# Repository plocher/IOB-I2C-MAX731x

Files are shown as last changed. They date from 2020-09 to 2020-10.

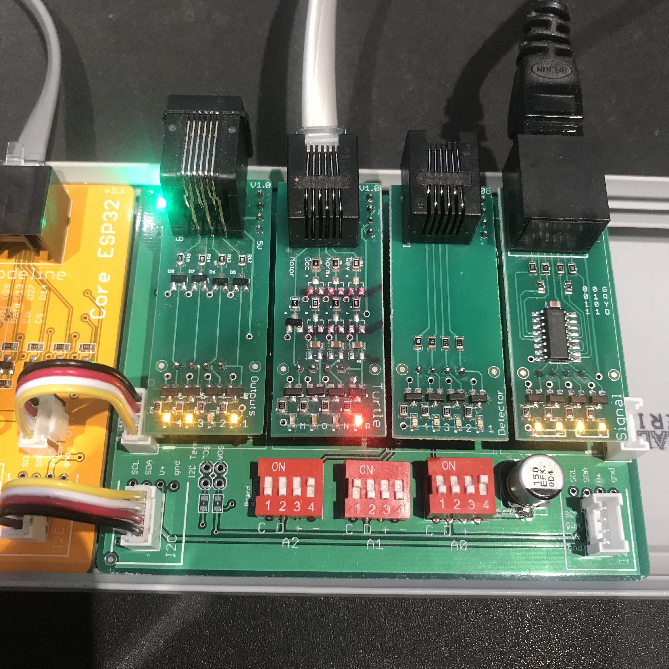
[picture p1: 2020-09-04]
IOB-I2C-MAX731x-photo.JPG

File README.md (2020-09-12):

# IOB-I2C-MAX731x
## License: CERN Open Hardware Licence v1.2

IOB I2C MAX7311/7318 based IO Expander

The MAX 731x series costs twice that of the MCP23017/PCA9555 expanders; for that price one gets support for  up to 64x devices on a single I2C chain.

### Specifications

This board is based on the MAX7311/7318 16 bit IO Expander, which supports up to 64x instances.

Each board provides a latched set of 16x IO points, with each point
being software selectable to be either an input or an output. The
individual points are reasonably protected from the environment, and can
sink 10 mA each (they are NOT current sources!)
By using active low inputs and outputs, the effects of environmental noise are
reduced - remote sensors only need to ground an I/O point to register
activity.

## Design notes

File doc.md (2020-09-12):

# IOB-I2C-MAX731x
## License: CERN Open Hardware Licence v1.2
### Introduction

IOB I2C MAX7311/7318 based IO Expander

The MAX 731x series costs twice that of the MCP23017/PCA9555 expanders; for that price one gets support for  up to 64x devices on a single I2C chain.

This board was originally produced to help me build control panels for
my model railroad - I needed to connect many different buttons, switches
and lights to an Arduino, and also connect the Arduino to a
communications bus (Ethernet, CAN or Loconet), and I couldn\'t find
anything that had both high IO point density AND visual feedback.

I started with a simple I2C based 32-pin Arduino
[IOShield](/pages/IOShield "wikilink") with monitoring LEDs on each pin
(Active-LOW inputs, LED is on when pin is grounded, writing a \"1\" to
the port pulls it to ground). I was aiming to support up to the max I2C
devices that can be used together, with the 8-bit board
[I2C-8574-IO](/pages/I2C-8574-IO "wikilink") (deprecated), that was a total of
8x boards with 128 i/o points.

The 7311 IO expanders used here will support up to 64 boards, with 1024
potential I/O points.

This latest design moves from overly generic and/or overly specialized
designs to a generic design with daughterboards that encapsulate the
appliance-specific buffering and logic. The benefits provided by these
IOB boards include:

-   Improved I/O bank utilization (leftover capacity is now a multiple
    of 4-bit daughtercard instead of 16-bit I2C card\...)
-   Riser height eliminates having to custom cut 3M track
-   Allows deprecation of cabling intensive signal driver IO4 and I2C
    boards
-   Allows custom circuitry to be added to Signal, Detector and Turtle
    drivers

### Cautions

With several hundred IO loads, and up to 256 external breakout devices,
a suitable power supply (or supplies) must be used.

In practice, a 3A 9-12VDC supply a good choice for most small to medium
sized control points.

This supply needs to power the core processor, its direct IO loads, the
I2C expander chain AND provide \~100mA to each IO4 device. Instead of
relying on the Arduino\'s onboard regulated supply (which is only good
for about 100mA itself), each board has its own regulator with a common
supply feed that can handle up to 4A @ 12v. If more power is needed, the
daisy chained power feed thru can be replaced with a per-board
independent supply.

### Specifications

This IO board is based on the MAX7311/18 16 bit IO Expander, mounted on a
[IOB Baseboard](/pages/IOB-Baseboard "wikilink") that presents a
bank of 4x I/O personality boards (IOBs). The Baseboard contains buffered LED drivers connected
to LEDs that show the status of the I/O lines in real time. They also
contain the needed circuitry to drive / sense the appliances connected
to them. See

-   [IOB-Inputs](/pages/IOB-Inputs "wikilink") 4x buffered inputs
-   [IOB-Outputs](/pages/IOB-Outputs "wikilink") 4x buffered outputs
-   [IOB-Turtle](/pages/IOB-Turtle "wikilink") 1x buffered output and 3x buffered inputs
-   [IOB-Generic](/pages/IOB-Generic "wikilink") 4x unbuffered I/O lines with optional inline resistors

Each board provides a latched set of 16x IO points, with each point
being software selectable to be either an input or an output. The
individual points are reasonably protected from the environment, and can
sink 10 mA each (they are NOT current sources!)
By using active low inputs and outputs, the effects of environmental noise are
reduced - remote sensors only need to ground an I/O point to register
activity.

### Communication Protocol

```C++
Simple I2C 16-bit Reads and Writes:
uint16_t I2Cexpander::read7311() {
    uint16_t data = 0;
    Wire.beginTransmission(_i2c_address);
    Wire.write(REGISTER_7311INPUT);
    Wire.endTransmission();
    // Wire.beginTransmission(_i2c_address);
    Wire.requestFrom(_i2c_address, (uint8_t)2);
    if(Wire.available()) {
        data = Wire.read();
    }
    if(Wire.available()) {
        data |= (Wire.read() << 8);
    }
    // Wire.endTransmission();
    return data;
}

void I2Cexpander::write7311(uint16_t data) {
    data = data | _config;
    Wire.beginTransmission(_i2c_address);
    Wire.write(REGISTER_7311OUTPUT);
    Wire.write(0xff & data);  //  low byte
    Wire.write(data >> 8);    //  high byte
    Wire.endTransmission();
}
```

See [I2Cexpander-lib](/pages/I2Cexpander "wikilink") for a more complete interface
library.

### Addressing
The address selection for the MAX731x is complex, as it uses 3x address pins, but adds SDA and SCL to the traditional "Vcc and Gnd" used elsewhere.

**AD2**|**AD1**|**AD0**|**A6**|**A5**|**A4**|**A3**|**A2**|**A1**|**A0**|**ADDRESS (HEX)**
:-----:|:-----:|:-----:|:-----:|:-----:|:-----:|:-----:|:-----:|:-----:|:-----:|:-----:
GND|SCL|GND|0|0|1|0|0|0|0|0x20
GND|SCL|V+|0|0|1|0|0|0|1|0x22
GND|SDA|GND|0|0|1|0|0|1|0|0x24
GND|SDA|V+|0|0|1|0|0|1|1|0x26
V+|SCL|GND|0|0|1|0|1|0|0|0x28
V+|SCL|V+|0|0|1|0|1|0|1|0x2A
V+|SDA|GND|0|0|1|0|1|1|0|0x2C
V+|SDA|V+|0|0|1|0|1|1|1|0x2E
GND|SCL|SCL|0|0|1|1|0|0|0|0x30
GND|SCL|SDA|0|0|1|1|0|0|1|0x32
GND|SDA|SCL|0|0|1|1|0|1|0|0x34
GND|SDA|SDA|0|0|1|1|0|1|1|0x36
V+|SCL|SCL|0|0|1|1|1|0|0|0x38
V+|SCL|SDA|0|0|1|1|1|0|1|0x3A
V+|SDA|SCL|0|0|1|1|1|1|0|0x3C
V+|SDA|SDA|0|0|1|1|1|1|1|0x3E
GND|GND|GND|0|1|0|0|0|0|0|0x40
GND|GND|V+|0|1|0|0|0|0|1|0x42
GND|V+|GND|0|1|0|0|0|1|0|0x44
GND|V+|V+|0|1|0|0|0|1|1|0x46
V+|GND|GND|0|1|0|0|1|0|0|0x48
V+|GND|V+|0|1|0|0|1|0|1|0x4A
V+|V+|GND|0|1|0|0|1|1|0|0x4C
V+|V+|V+|0|1|0|0|1|1|1|0x4E
GND|GND|SCL|0|1|0|1|0|0|0|0x50
GND|GND|SDA|0|1|0|1|0|0|1|0x52
GND|V+|SCL|0|1|0|1|0|1|0|0x54
GND|V+|SDA|0|1|0|1|0|1|1|0x56
V+|GND|SCL|0|1|0|1|1|0|0|0x58
V+|GND|SDA|0|1|0|1|1|0|1|0x5A
V+|V+|SCL|0|1|0|1|1|1|0|0x5C
V+|V+|SDA|0|1|0|1|1|1|1|0x5E
SCL|SCL|GND|1|0|1|0|0|0|0|0xA0
SCL|SCL|V+|1|0|1|0|0|0|1|0xA2
SCL|SDA|GND|1|0|1|0|0|1|0|0xA4
SCL|SDA|V+|1|0|1|0|0|1|1|0xA6
SDA|SCL|GND|1|0|1|0|1|0|0|0xA8
SDA|SCL|V+|1|0|1|0|1|0|1|0xAA
SDA|SDA|GND|1|0|1|0|1|1|0|0xAC
SDA|SDA|V+|1|0|1|0|1|1|1|0xAE
SCL|SCL|SCL|1|0|1|1|0|0|0|0xB0
SCL|SCL|SDA|1|0|1|1|0|0|1|0xB2
SCL|SDA|SCL|1|0|1|1|0|1|0|0xB4
SCL|SDA|SDA|1|0|1|1|0|1|1|0xB6
SDA|SCL|SCL|1|0|1|1|1|0|0|0xB8
SDA|SCL|SDA|1|0|1|1|1|0|1|0xBA
SDA|SDA|SCL|1|0|1|1|1|1|0|0xBC
SDA|SDA|SDA|1|0|1|1|1|1|1|0xBE
SCL|GND|GND|1|1|0|0|0|0|0|0xC0
SCL|GND|V+|1|1|0|0|0|0|1|0xC2
SCL|V+|GND|1|1|0|0|0|1|0|0xC4
SCL|V+|V+|1|1|0|0|0|1|1|0xC6
SDA|GND|GND|1|1|0|0|1|0|0|0xC8
SDA|GND|V+|1|1|0|0|1|0|1|0xCA
SDA|V+|GND|1|1|0|0|1|1|0|0xCC
SDA|V+|V+|1|1|0|0|1|1|1|0xCE
SCL|GND|SCL|1|1|0|1|0|0|0|0xD0
SCL|GND|SDA|1|1|0|1|0|0|1|0xD2
SCL|V+|SCL|1|1|0|1|0|1|0|0xD4
SCL|V+|SDA|1|1|0|1|0|1|1|0xD6
SDA|GND|SCL|1|1|0|1|1|0|0|0xD8
SDA|GND|SDA|1|1|0|1|1|0|1|0xDA
SDA|V+|SCL|1|1|0|1|1|1|0|0xDC
SDA|V+|SDA|1|1|0|1|1|1|1|0xDE

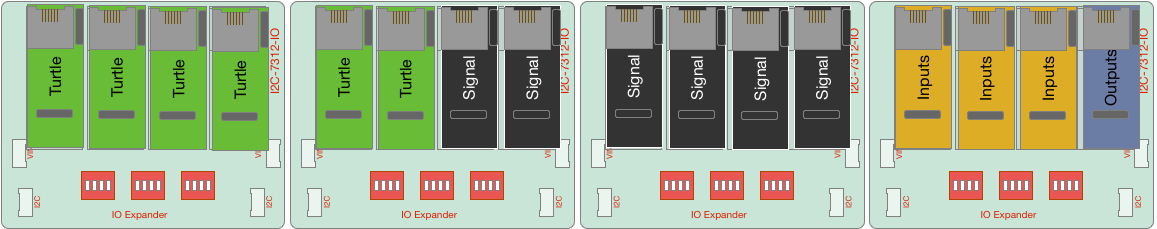
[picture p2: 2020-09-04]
IOB-I2C-MAX731x-Graphic-set.png

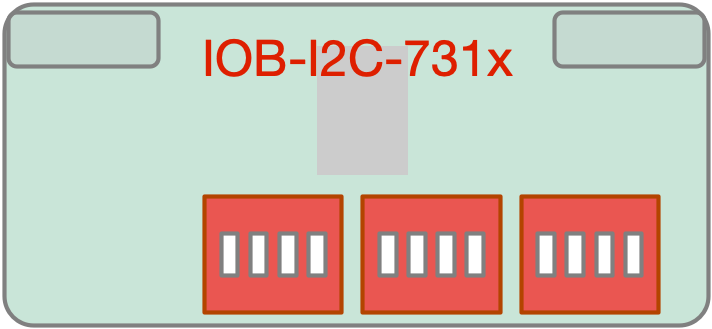
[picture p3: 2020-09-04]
IOB-I2C-MAX731x-Graphic.png

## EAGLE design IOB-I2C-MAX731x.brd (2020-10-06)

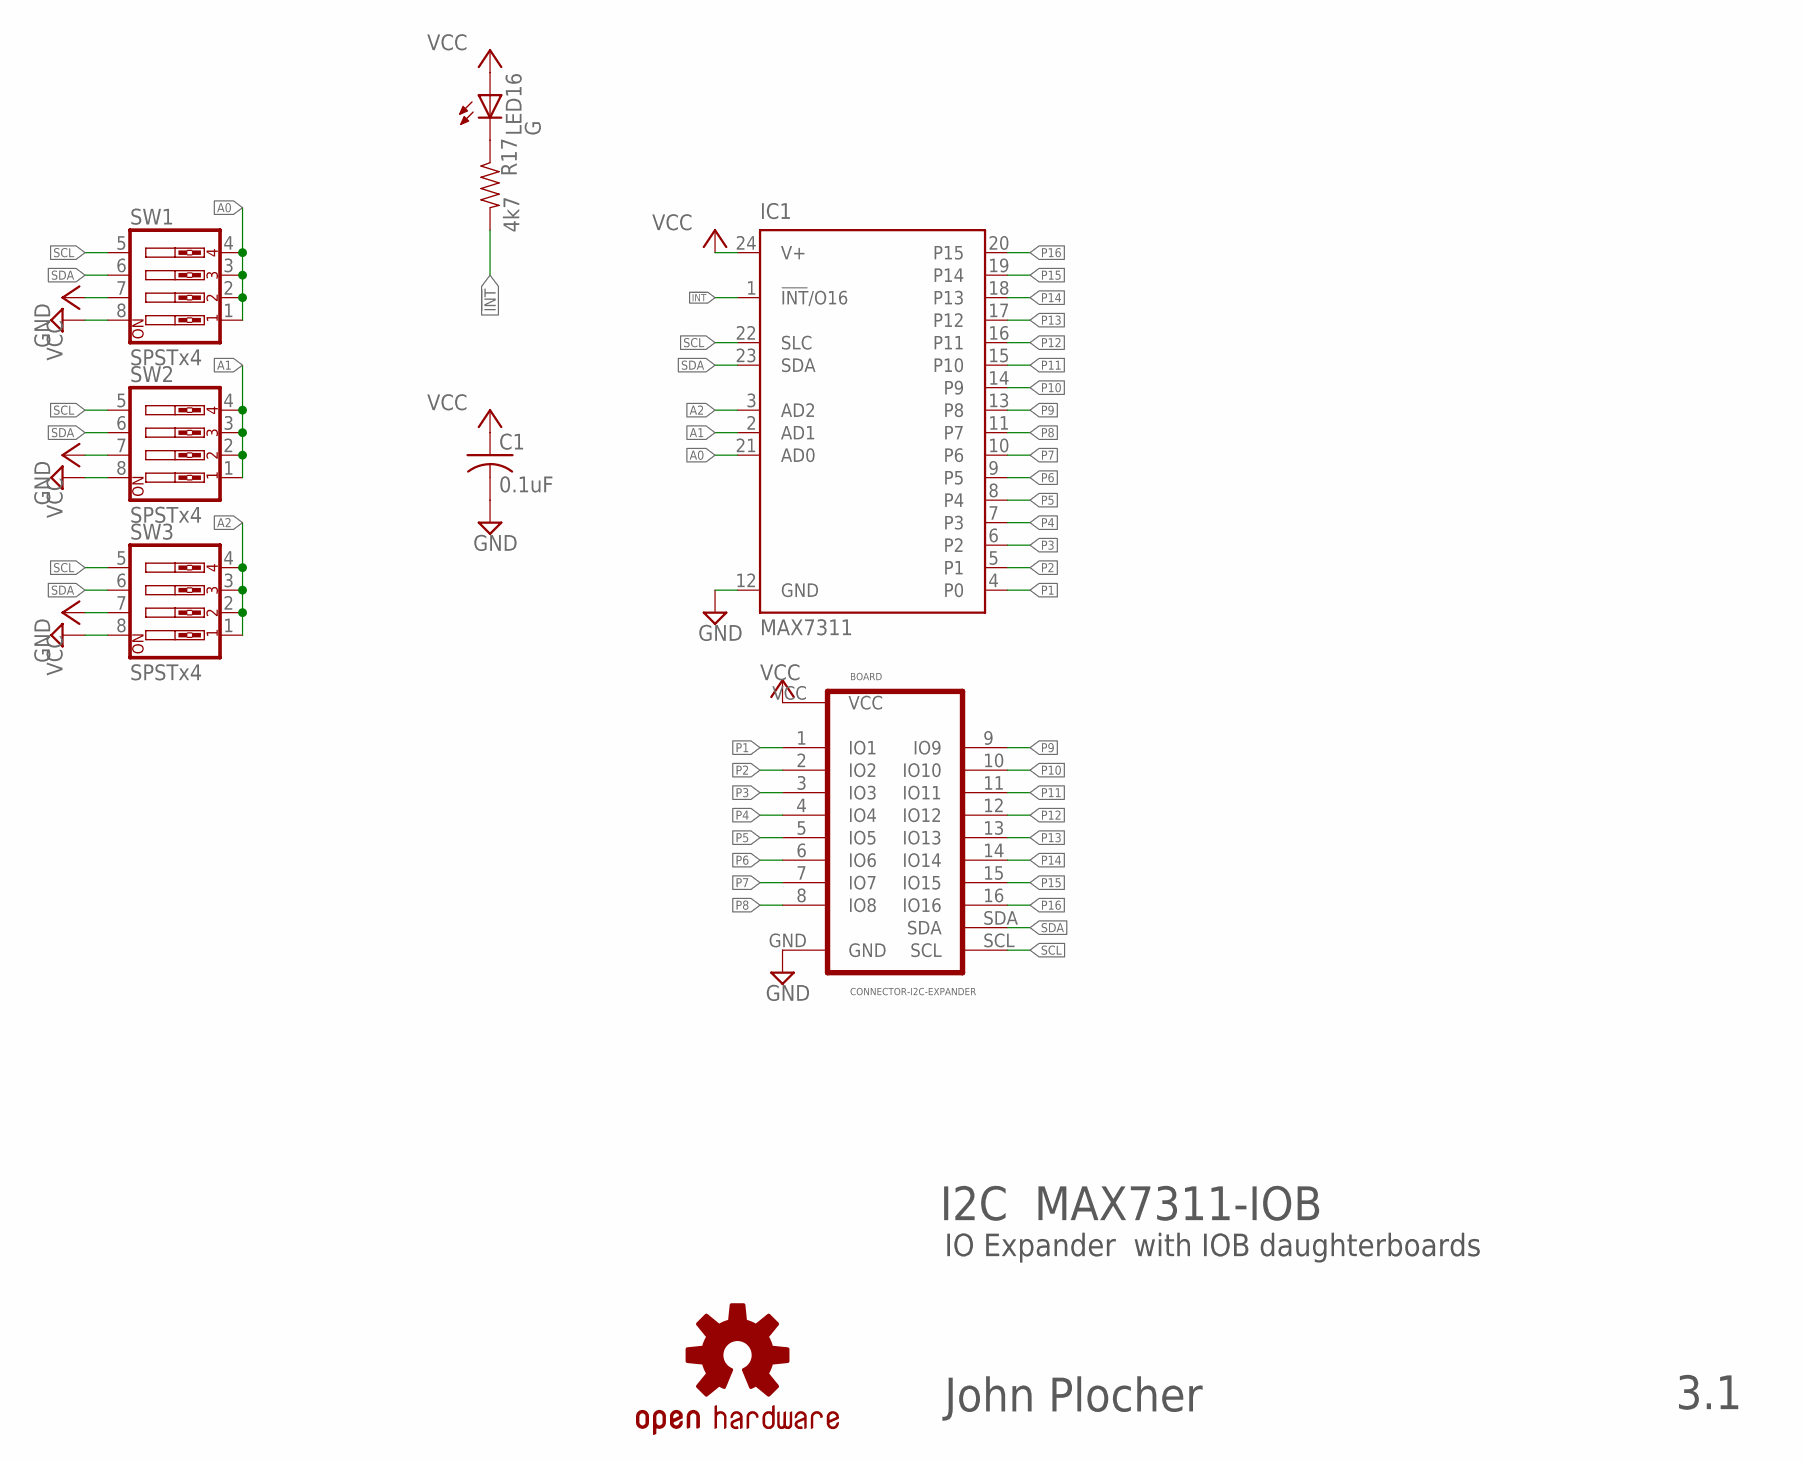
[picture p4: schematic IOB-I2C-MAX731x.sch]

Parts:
BOARD: CONNECTOR-I2C-EXPANDER; I2C-EXPANDER
C1: 0.1uF; 0603-CAP
IC1: MAX7311; TSSOP24
LED16: G; 0603-LED
R17: 4k7; 0603-RES
SW1, SW2, SW3: SPSTx4; EDG-04
U$1: OSHW; OSHW-LOGO-L

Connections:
!INT: IC1.1 (!INT!/O16), R17.2
A0: IC1.21 (AD0), SW1.1, SW1.2, SW1.3, SW1.4
A1: IC1.2 (AD1), SW2.1, SW2.2, SW2.3, SW2.4
A2: IC1.3 (AD2), SW3.1, SW3.2, SW3.3, SW3.4
GND: BOARD.GND, C1.2, IC1.12 (GND), SW1.8, SW2.8, SW3.8
unnamed: LED16.C, R17.1
P1: BOARD.1 (IO1), IC1.4 (P0)
P2: BOARD.2 (IO2), IC1.5 (P1)
P3: BOARD.3 (IO3), IC1.6 (P2)
P4: BOARD.4 (IO4), IC1.7 (P3)
P5: BOARD.5 (IO5), IC1.8 (P4)
P6: BOARD.6 (IO6), IC1.9 (P5)
P7: BOARD.7 (IO7), IC1.10 (P6)
P8: BOARD.8 (IO8), IC1.11 (P7)
P9: BOARD.9 (IO9), IC1.13 (P8)
P10: BOARD.10 (IO10), IC1.14 (P9)
P11: BOARD.11 (IO11), IC1.15 (P10)
P12: BOARD.12 (IO12), IC1.16 (P11)
P13: BOARD.13 (IO13), IC1.17 (P12)
P14: BOARD.14 (IO14), IC1.18 (P13)
P15: BOARD.15 (IO15), IC1.19 (P14)
P16: BOARD.16 (IO16), IC1.20 (P15)
SCL: BOARD.SCL, IC1.22 (SLC), SW1.5, SW2.5, SW3.5
SDA: BOARD.SDA, IC1.23 (SDA), SW1.6, SW2.6, SW3.6
VCC: BOARD.VCC, C1.1, IC1.24 (V+), LED16.A, SW1.7, SW2.7, SW3.7

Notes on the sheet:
I2C MAX7311-IOB
IO Expander with IOB daughterboards
John Plocher
3.1

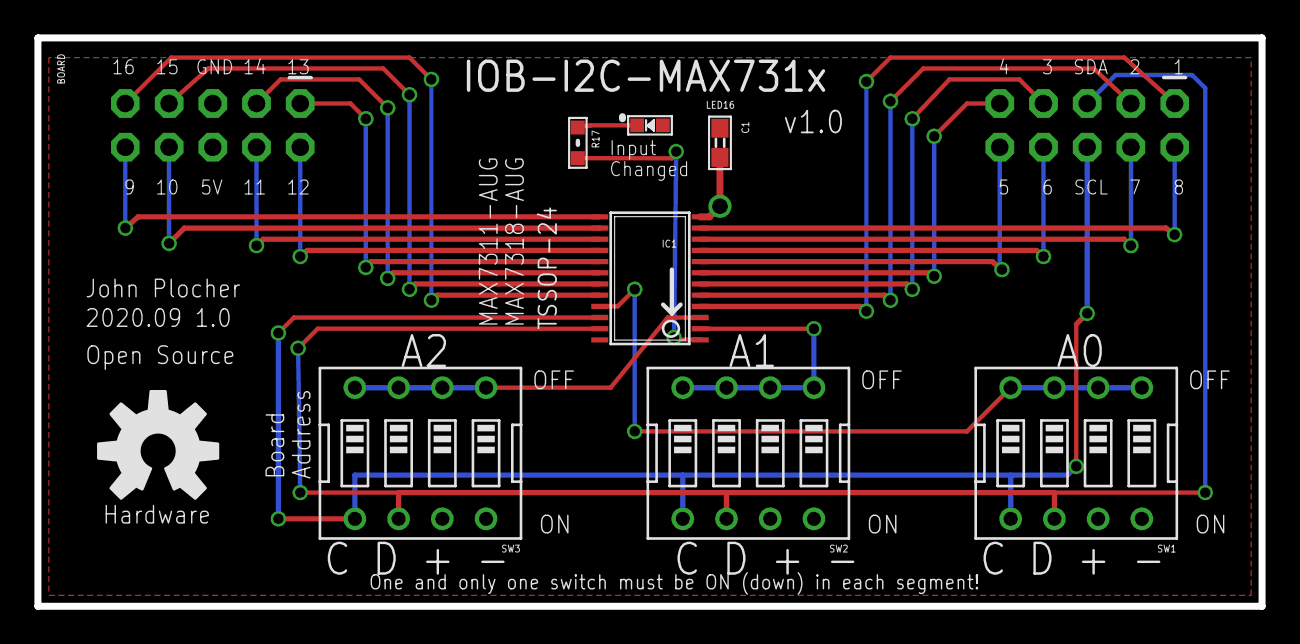
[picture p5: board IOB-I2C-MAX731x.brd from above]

Board: 2 copper layers, 71.1 x 33.0 mm, 9 parts (0 on the bottom side), 25 nets.

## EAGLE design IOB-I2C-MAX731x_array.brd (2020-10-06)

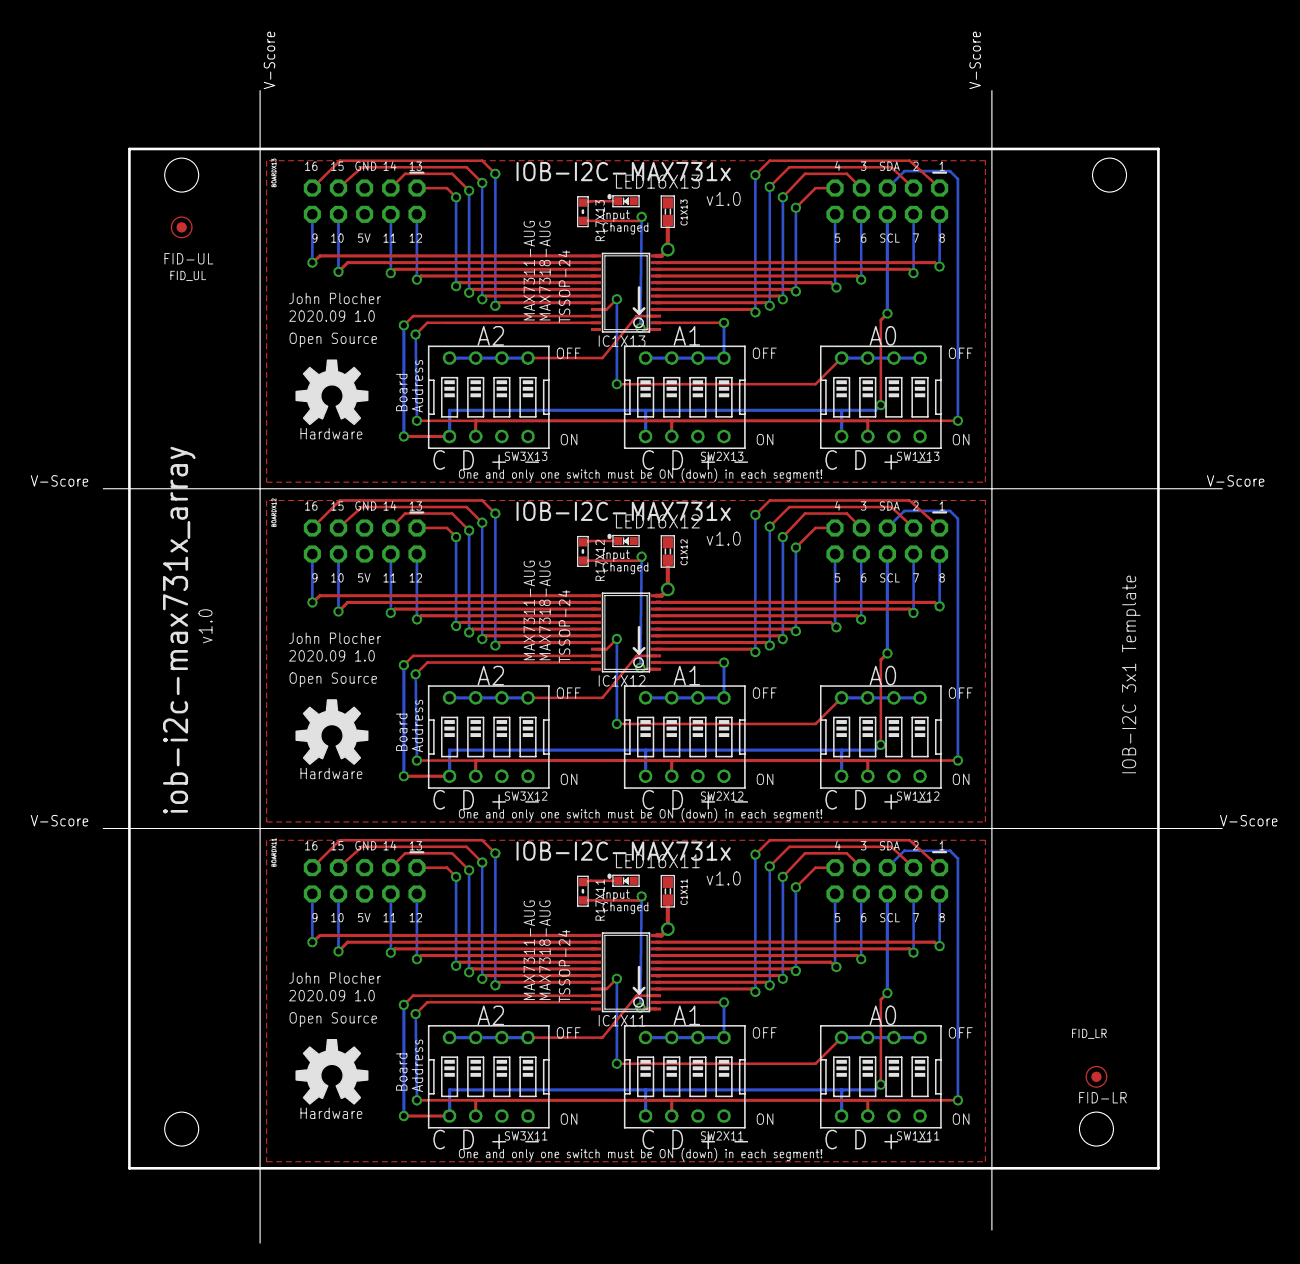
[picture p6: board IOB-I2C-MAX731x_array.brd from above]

Board: 2 copper layers, 108.7 x 112.0 mm, 30 parts (0 on the bottom side), 75 nets.

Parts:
BOARDX11, BOARDX12, BOARDX13: CONNECTOR-I2C-EXPANDER; I2C-EXPANDER
C1X11, C1X12, C1X13: 0.1uF; 0603-CAP
FID-LR: FIDUCIAL; FIDUCIAL_1MM
FID-UL: FIDUCIAL; FIDUCIAL_1MM
IC1X11, IC1X12, IC1X13: MAX7311; TSSOP24
LED16X11, LED16X12, LED16X13: G; 0603-LED
R17X11, R17X12, R17X13: 4k7; 0603-RES
SW1X11, SW1X12, SW1X13, SW2X11, SW2X12, SW2X13, SW3X11, SW3X12, SW3X13: SPSTx4; EDG-04
U$1X11, U$1X12, U$1X13: DOC-OSHW-LOGO-L; OSHW-LOGO-L
U$5X1: BOARD; BOARD-TEMPLATE-IOB-I2C-3X1-ARRAY

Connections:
!INTX11: IC1X11.1, R17X11.2
!INTX12: IC1X12.1, R17X12.2
!INTX13: IC1X13.1, R17X13.2
A0X11: IC1X11.21, SW1X11.1, SW1X11.2, SW1X11.3, SW1X11.4
A0X12: IC1X12.21, SW1X12.1, SW1X12.2, SW1X12.3, SW1X12.4
A0X13: IC1X13.21, SW1X13.1, SW1X13.2, SW1X13.3, SW1X13.4
A1X11: IC1X11.2, SW2X11.1, SW2X11.2, SW2X11.3, SW2X11.4
A1X12: IC1X12.2, SW2X12.1, SW2X12.2, SW2X12.3, SW2X12.4
A1X13: IC1X13.2, SW2X13.1, SW2X13.2, SW2X13.3, SW2X13.4
A2X11: IC1X11.3, SW3X11.1, SW3X11.2, SW3X11.3, SW3X11.4
A2X12: IC1X12.3, SW3X12.1, SW3X12.2, SW3X12.3, SW3X12.4
A2X13: IC1X13.3, SW3X13.1, SW3X13.2, SW3X13.3, SW3X13.4
GNDX11: BOARDX11.GND, C1X11.2, IC1X11.12, SW1X11.8, SW2X11.8, SW3X11.8
GNDX12: BOARDX12.GND, C1X12.2, IC1X12.12, SW1X12.8, SW2X12.8, SW3X12.8
GNDX13: BOARDX13.GND, C1X13.2, IC1X13.12, SW1X13.8, SW2X13.8, SW3X13.8
unnamed: LED16X11.C, R17X11.1
unnamed: LED16X12.C, R17X12.1
unnamed: LED16X13.C, R17X13.1
P1X11: BOARDX11.1, IC1X11.4
P1X12: BOARDX12.1, IC1X12.4
P1X13: BOARDX13.1, IC1X13.4
P2X11: BOARDX11.2, IC1X11.5
P2X12: BOARDX12.2, IC1X12.5
P2X13: BOARDX13.2, IC1X13.5
P3X11: BOARDX11.3, IC1X11.6
P3X12: BOARDX12.3, IC1X12.6
P3X13: BOARDX13.3, IC1X13.6
P4X11: BOARDX11.4, IC1X11.7
P4X12: BOARDX12.4, IC1X12.7
P4X13: BOARDX13.4, IC1X13.7
P5X11: BOARDX11.5, IC1X11.8
P5X12: BOARDX12.5, IC1X12.8
P5X13: BOARDX13.5, IC1X13.8
P6X11: BOARDX11.6, IC1X11.9
P6X12: BOARDX12.6, IC1X12.9
P6X13: BOARDX13.6, IC1X13.9
P7X11: BOARDX11.7, IC1X11.10
P7X12: BOARDX12.7, IC1X12.10
P7X13: BOARDX13.7, IC1X13.10
P8X11: BOARDX11.8, IC1X11.11
P8X12: BOARDX12.8, IC1X12.11
P8X13: BOARDX13.8, IC1X13.11
P9X11: BOARDX11.9, IC1X11.13
P9X12: BOARDX12.9, IC1X12.13
P9X13: BOARDX13.9, IC1X13.13
P10X11: BOARDX11.10, IC1X11.14
P10X12: BOARDX12.10, IC1X12.14
P10X13: BOARDX13.10, IC1X13.14
P11X11: BOARDX11.11, IC1X11.15
P11X12: BOARDX12.11, IC1X12.15
P11X13: BOARDX13.11, IC1X13.15
P12X11: BOARDX11.12, IC1X11.16
P12X12: BOARDX12.12, IC1X12.16
P12X13: BOARDX13.12, IC1X13.16
P13X11: BOARDX11.13, IC1X11.17
P13X12: BOARDX12.13, IC1X12.17
P13X13: BOARDX13.13, IC1X13.17
P14X11: BOARDX11.14, IC1X11.18
P14X12: BOARDX12.14, IC1X12.18
P14X13: BOARDX13.14, IC1X13.18
P15X11: BOARDX11.15, IC1X11.19
P15X12: BOARDX12.15, IC1X12.19
P15X13: BOARDX13.15, IC1X13.19
P16X11: BOARDX11.16, IC1X11.20
P16X12: BOARDX12.16, IC1X12.20
P16X13: BOARDX13.16, IC1X13.20
SCLX11: BOARDX11.SCL, IC1X11.22, SW1X11.5, SW2X11.5, SW3X11.5
SCLX12: BOARDX12.SCL, IC1X12.22, SW1X12.5, SW2X12.5, SW3X12.5
SCLX13: BOARDX13.SCL, IC1X13.22, SW1X13.5, SW2X13.5, SW3X13.5
SDAX11: BOARDX11.SDA, IC1X11.23, SW1X11.6, SW2X11.6, SW3X11.6
SDAX12: BOARDX12.SDA, IC1X12.23, SW1X12.6, SW2X12.6, SW3X12.6
SDAX13: BOARDX13.SDA, IC1X13.23, SW1X13.6, SW2X13.6, SW3X13.6
VCCX11: BOARDX11.VCC, C1X11.1, IC1X11.24, LED16X11.A, SW1X11.7, SW2X11.7, SW3X11.7
VCCX12: BOARDX12.VCC, C1X12.1, IC1X12.24, LED16X12.A, SW1X12.7, SW2X12.7, SW3X12.7
VCCX13: BOARDX13.VCC, C1X13.1, IC1X13.24, LED16X13.A, SW1X13.7, SW2X13.7, SW3X13.7

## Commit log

2020-09-04 Initial version
    [IOB-I2C-MAX731x.brd, IOB-I2C-MAX731x.sch, IOB-I2C-MAX731x_array.brd]
2020-09-11 cleanup layout
    [IOB-I2C-MAX731x.brd, IOB-I2C-MAX731x.sch, IOB-I2C-MAX731x_array.brd]
2020-10-05 added values for connectors
    [IOB-I2C-MAX731x_array.brd]
2020-10-06 normalized values
    [IOB-I2C-MAX731x.brd, IOB-I2C-MAX731x.sch, IOB-I2C-MAX731x_array.brd]

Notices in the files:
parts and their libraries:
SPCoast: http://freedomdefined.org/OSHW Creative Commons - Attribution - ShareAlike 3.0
